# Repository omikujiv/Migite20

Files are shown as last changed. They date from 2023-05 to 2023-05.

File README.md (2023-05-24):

# Migite20
DIY Keyboard that has 21 key and 3 encoder, for Right hand 

## 左利きユーザ向けの右手デバイス。  
## お絵かき用途などに。

## 驚異のロータリーエンコーダー3積で、様々な直観的な操作に対応。  
## ロータリーエンコーダは親指や人差し指での操作を想定。  
IMGP3940
IMGP3948
# 仕様/キーマップ
ハードウェア上では、次のようにキーが浅いんされている。
この時、Zはロータリーエンコーダの押し込みボタンである。
（つまみが平たい円の物）

                ┌───┬───┬───┐  
                │ 2 │ 3 │ 4 │  
            ┌───┼───┼───┼───┤  
            │ 1 │ 6 │ 7 │ 8 │  
            ├───┼───┼───┤───│  
            │ 5 │ 0 │ A │ B │  
            ├───┼───┼───┼───┤  
            │ 9 │ D │ E │ F │  
    ┌───┐   ├───┼───┼───┤───┤  
    │ Z │   │ C | H │ I │ J │  
    └───┘   ├───┴───┴───┴───┘  
            │ G │
            └───┘

ソフトウェア上では、次のようなキーマトリクスとして処理されている。

    ┌───┬───┬───┬───┐  
    │ 1 │ 2 │ 3 │ 4 │  
    ├───┼───┼───┼───┤  
    │ 5 │ 6 │ 7 │ 8 │  
    ├───┼───┼───┤───│  
    │ 9 │ 0 │ A │ B │  
    ├───┼───┼───┼───┤  
    │ C │ D │ E │ F │  
    ├───┼───┼───┤───┼───┐  
    │ G | H │ I │ J │ Z │  
    └───┴───┴───┴───┴───┘  

ロータリエンコーダは任意角度回転時にキーが1回入力される。  
回し続けると連続入力される。

# 回路/配線
回路はキースイッチ対応箇所が $4\times 5$のキーマトリクス

ロータリーエンコーダは1つにつき2つの信号線と、1つのグランド  
ロータリーエンコーダのスイッチは行の配線はマトリクスから拝借（拡張）、列のは単独でピンを設定

ここまでの信号ピンの合計

$キーマトリクス: 4 + 5=9$ 

$ロータリエンコーダ： 2 \times 3=6 $

$ロータリエンコーダのスイッチ：1$

$合計：16 ピン$

promicroは18ピンくらいまで信号を扱えるので、ピン数は結構ギリギリとなっている。

実際の配線は漢のジャンパワイヤによる空中配線
IMGP3945

# 筐体/ハードウェア
- 白いメイン部分 & エンコーダつまみ：3Dプリンタ(FDM)
- マウスホイール型エンコーダつまみ：100均マウスから拝借
- 底面透明部：アクリル板(1.8mm)をはんだごてで切り出し
- キースイッチ：Kailh Box V2 Switch / Red / Linear
    - https://shop.yushakobo.jp/products/4264
- キーキャップ：Doys A Kit (Warm white)
    - https://shop.yushakobo.jp/products/6918
- 底面滑り止め：100均滑り止めシート

# 筐体データ説明 in 3Dprint_data
- ## migite_ob1.stl  
    キーキャップを差し込むパーツ  
    印刷の都合で裏表が反対


- ## migite_part.stl
    ロータリーエンコーダや回路を配置するパーツ  
    印刷の都合で裏表が反対


- ## migite_bla.stl
    1枚目のユニバーサル基板と2枚目のユニバーサル基板をつなぐブラケットパーツ  
    四方を囲むとマウス型のロータリーエンコーダと干渉する  


- ## migite_NOBUlong.stl  
    背の高いノブ  
    歯車ツールを利用して作成  


- ## migite_nobu.stl 
    広い方のノブ   


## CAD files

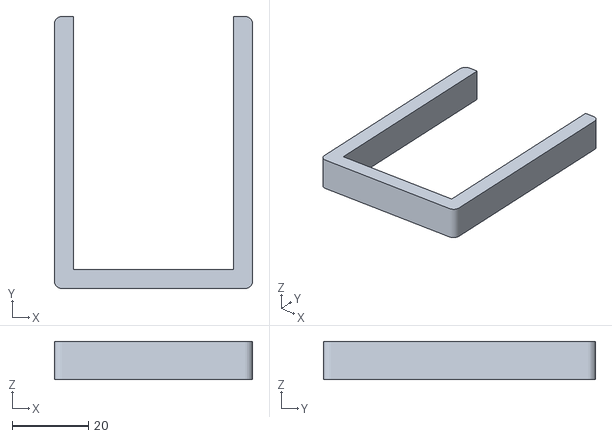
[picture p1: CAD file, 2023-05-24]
3Dprint_data/migite_bla.stl
52.1 x 71.4 x 10.0

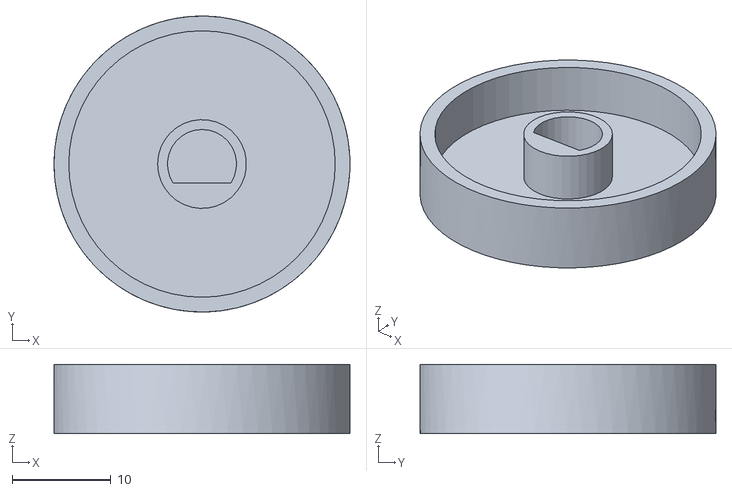
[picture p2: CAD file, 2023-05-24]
3Dprint_data/migite_nobu.stl
30.0 x 30.0 x 7.00

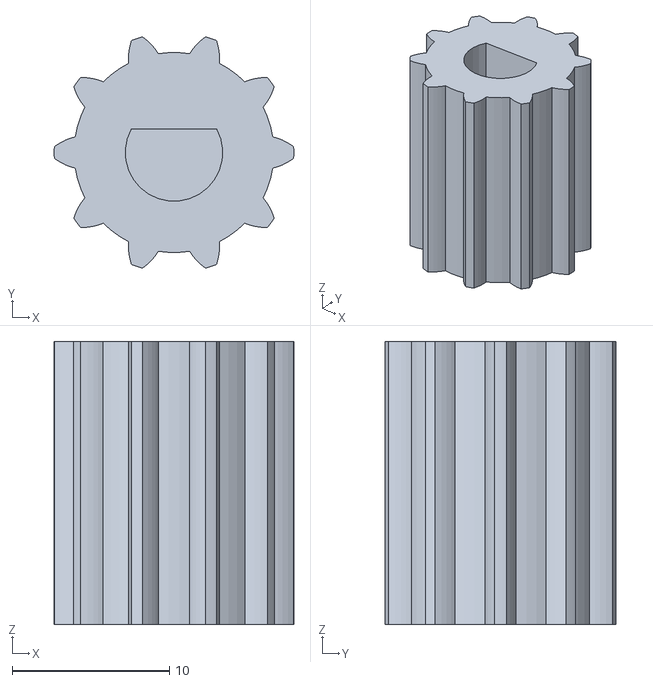
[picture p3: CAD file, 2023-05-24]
3Dprint_data/migite_NOBUlong.stl
15.2 x 14.7 x 18.0

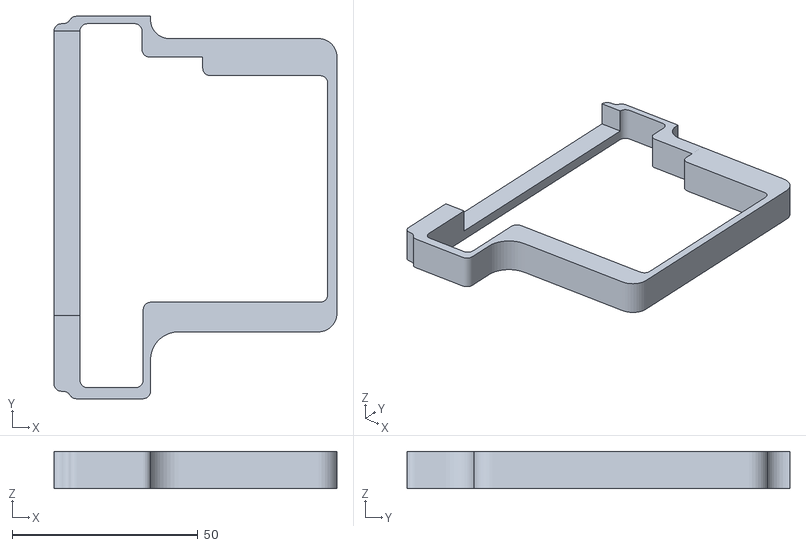
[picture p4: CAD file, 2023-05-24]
3Dprint_data/migite_part.stl
76.2 x 103.0 x 10.00

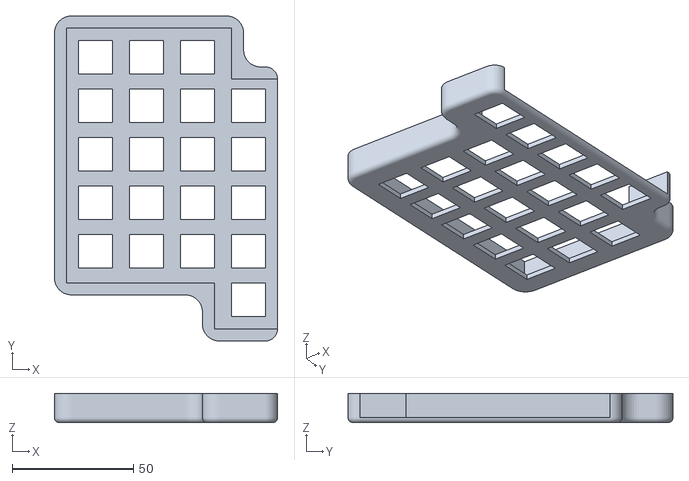
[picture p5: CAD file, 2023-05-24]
3Dprint_data/migite_ob1.stl
92.0 x 134.0 x 12.0

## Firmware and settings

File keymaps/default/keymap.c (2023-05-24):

// Copyright 2023 QMK
// SPDX-License-Identifier: GPL-2.0-or-later

#include QMK_KEYBOARD_H

// ENCODER_MAP_ENABLE = yes

const uint16_t PROGMEM keymaps[][MATRIX_ROWS][MATRIX_COLS] = {
    /*
     * ┌───┬───┬───┬───┐
     * │ 1 │ 2 │ 3 │ 4 │
     * ├───┼───┼───┼───┤
     * │ 5 │ 6 │ 7 │ 8 │
     * ├───┼───┼───┤───│
     * │ 9 │ 0 │ A │ B │
     * ├───┼───┼───┼───┤
     * │ C │ D │ E │ F │
     * ├───┼───┼───┤───│
     * │ G | H │ I │ J │ Z
     * └───┴───┴───┴───┘
     */
    [0] = LAYOUT_numpad_5x4(
        KC_P1,   KC_P2,   KC_P3,   KC_P4,
        KC_P5,   KC_P6,   KC_P7,   KC_P8,
        KC_P9,   KC_P0,   KC_A,    KC_B,
        KC_C,    KC_D,    KC_E,    KC_F,
        KC_G,    KC_H,    KC_I,    KC_J, KC_Z
    )
};


bool encoder_update_user(uint8_t index, bool clockwise) {
    if (index == 0) { /* First encoder */
        if (clockwise) {
            tap_code(KC_K);
        } else {
            tap_code(KC_L);
        }
    } else if (index == 1) { /* Second encoder */
        if (clockwise) {
            tap_code(KC_N);
        } else {
            tap_code(KC_M);
        }
    } else if (index == 2) { /* Third encoder */
        if (clockwise) {
            tap_code(KC_O);
        } else {
            tap_code(KC_P);
        }
    }
    return false;
}
